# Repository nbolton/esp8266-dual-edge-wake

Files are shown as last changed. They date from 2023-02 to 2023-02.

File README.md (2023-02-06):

# ESP8266 dual edge wake

This module will wake an ESP8266 from deep sleep when a sensor value changes (e.g. push button, float sensor, or other reed sensor). 

**Disclaimer:** If you need to do this, then you should probably use a different MCU that supports deep sleep interrupt on edge. But, if like me, you bought many ESP8266s and want to use them in a project where you have this requirement...

Connect input to the sensor, and output to the RST pin on the ESP8266.



*Note: Above is Rev 1 (latest is Rev 1a)*

When the input changes (goes from high to low or low to high), a short pulse is generated on the output which wakes the ESP8266 from deep sleep.

mnL7V

Note: The blue line above is mis-labeled as Q1, and should read Q3.

MbJCn

Either circuit A or B can be used. A is a dual edge monostable trigger, and B is an edge to glitch conveter (XOR with delay). 
Solder the circuit jumper to choose between circuit A or B (the center pad is the input). 

For circuit A, solder either the leading or falling jumper (or both can be soldered to pulse on both edges).
For circuit B, a pulse will always be generated on both edges.

VCC min 2.5 V, max 6.0 V.

Example use case: Wake your ESP8266 and report a float sensor value change (e.g. when a water tank is full).



*Note: Resistor bodge was needed for board Rev 1 (now obsolete, replaced by Rev 1b which fixed the issue).*

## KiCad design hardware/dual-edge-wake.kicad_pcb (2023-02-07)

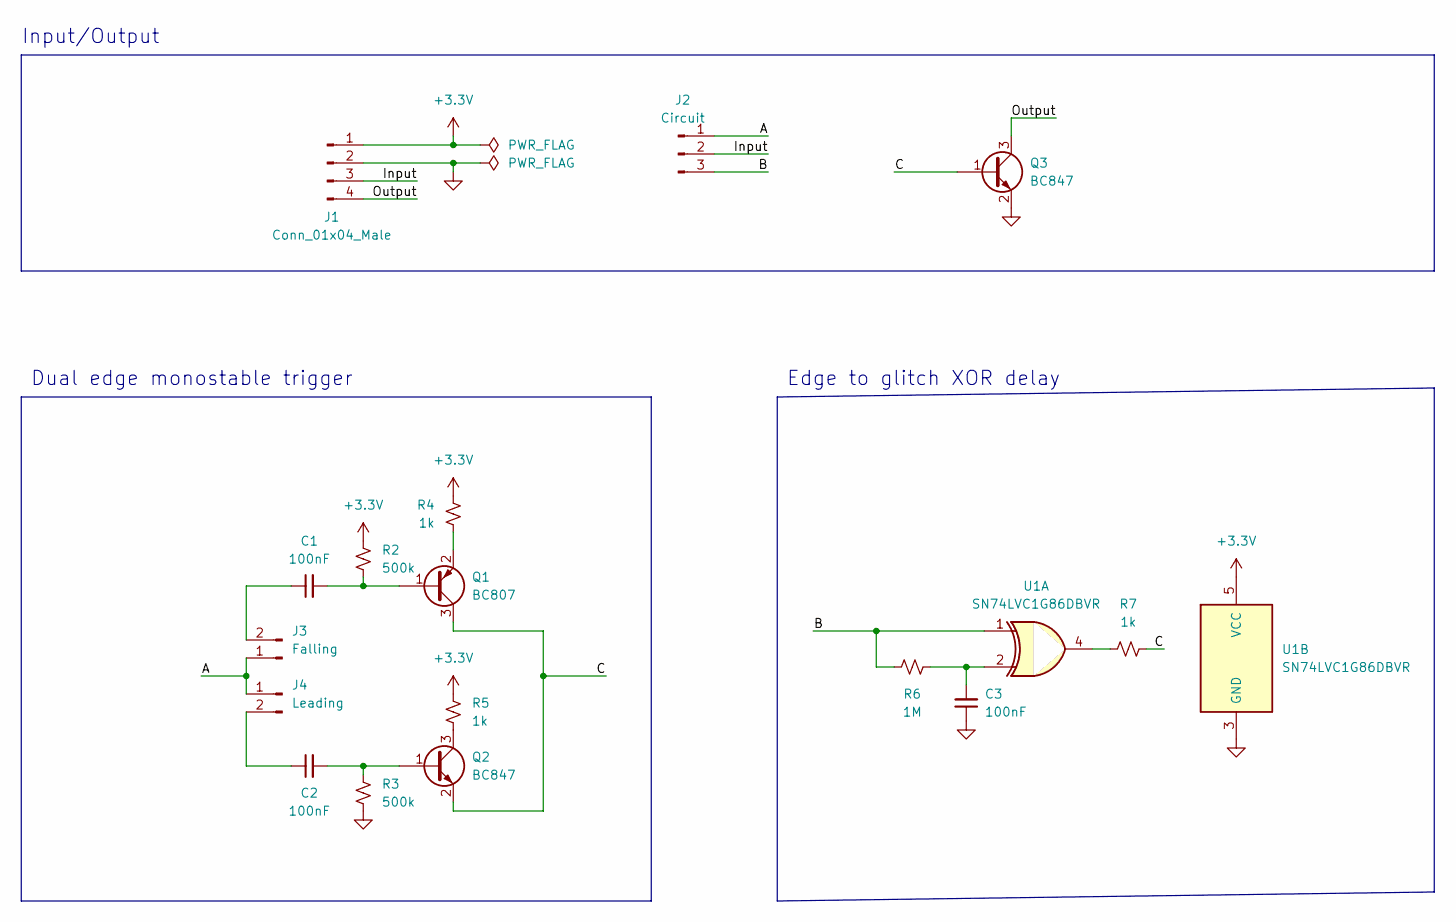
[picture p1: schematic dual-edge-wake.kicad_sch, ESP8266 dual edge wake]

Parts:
C1, C2, C3: 100nF; C_0805_2012Metric_Pad1.18x1.45mm_HandSolder; LCSC C1711
J1: Conn_01x04_Male; PinHeader_1x04_P2.54mm_Vertical
J2: Circuit; SolderJumper-3_P1.3mm_Open_RoundedPad1.0x1.5mm
J3: Falling; SolderJumper-2_P1.3mm_Open_RoundedPad1.0x1.5mm
J4: Leading; SolderJumper-2_P1.3mm_Open_RoundedPad1.0x1.5mm
Q1: BC807; SOT-23_Handsoldering; LCSC C88012
Q2, Q3: BC847; SOT-23_Handsoldering; LCSC C57668
R2, R3: 500k; R_0805_2012Metric_Pad1.20x1.40mm_HandSolder; LCSC C2077866
R4, R5, R7: 1k; R_0805_2012Metric_Pad1.20x1.40mm_HandSolder; LCSC C79496
R6: 1M; R_0805_2012Metric_Pad1.20x1.40mm_HandSolder; LCSC C413339
U1: SN74LVC1G86DBVR; SOT-23-5_HandSoldering; LCSC C402161

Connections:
+3.3V: J1.1, R2.1, R4.1, R5.1, U1.5 (VCC)
/A: J2.1, J3.1, J4.1
/B: J2.3, R6.2, U1.1
/C: Q1.3 (C), Q2.2 (E), Q3.1 (B), R7.2
/Input: J1.3, J2.2
/Output: J1.4, Q3.3 (C)
GND: C3.1, J1.2, Q3.2 (E), R3.1, U1.3 (GND)
unnamed: C1.1, J3.2
unnamed: C1.2, Q1.1 (B), R2.2
unnamed: C2.1, J4.2
unnamed: C2.2, Q2.1 (B), R3.2
unnamed: C3.2, R6.1, U1.2
unnamed: Q1.2 (E), R4.2
unnamed: Q2.3 (C), R5.2
unnamed: R7.1, U1.4

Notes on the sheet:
Edge to glitch XOR delay
Dual edge monostable trigger
Input/Output

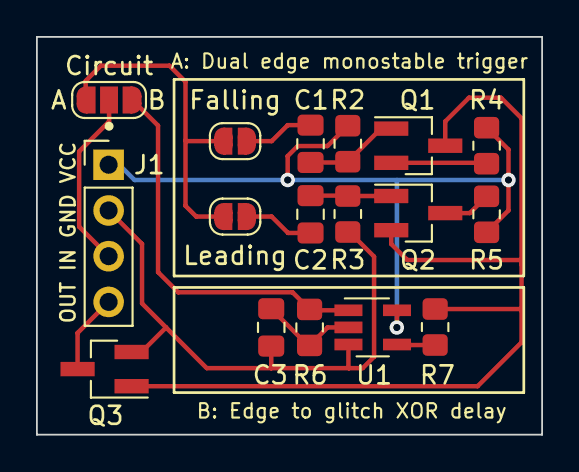
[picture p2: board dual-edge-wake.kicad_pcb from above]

Board: 2 copper layers, 28.1 x 22.1 mm, 17 parts (0 on the bottom side), 15 nets.

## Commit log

2023-01-28 WIP (need to fix alignment)
    [dual-edge-wake.kicad_pcb, dual-edge-wake.kicad_sch]
2023-01-28 Add custom RC jumper
    [dual-edge-wake.kicad_sch]
2023-01-28 Assign value to XOR
    [dual-edge-wake.kicad_sch]
2023-01-28 Assigned footprints and started PCB
    [dual-edge-wake.kicad_pcb, dual-edge-wake.kicad_sch]
2023-01-29 Finished first PCB
    [dual-edge-wake.kicad_pcb, dual-edge-wake.kicad_sch]
2023-01-29 Rename project dir
    [dual-edge-wake.kicad_pcb, dual-edge-wake.kicad_sch]
2023-02-06 Fixed #2
    Add resistor between circuit outputs, removed pull-up on circuit A input. Also add rear SS
    [dual-edge-wake.kicad_pcb, dual-edge-wake.kicad_sch]
2023-02-07 Tidied up SS, updated rev
    [dual-edge-wake.kicad_pcb, dual-edge-wake.kicad_sch]
